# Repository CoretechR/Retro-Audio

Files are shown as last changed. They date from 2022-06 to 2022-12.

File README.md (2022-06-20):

# DIY Retro Audio Player

Inspired by 1980s tape recorders, this audio player was designed with ease of use and accessibility in mind. Despite its nostalgic appearance, it packs modern hardware. Powered by the ESP32, it plays music and audiobooks from a micro SD card, either on its internal speaker or though a headphone jack. A 2.8“ IPS screen and mechanical buttons make up the simplistic user interface. The software is built around the ESP32-audioI2S library by GitHub user Schreibfaul1.

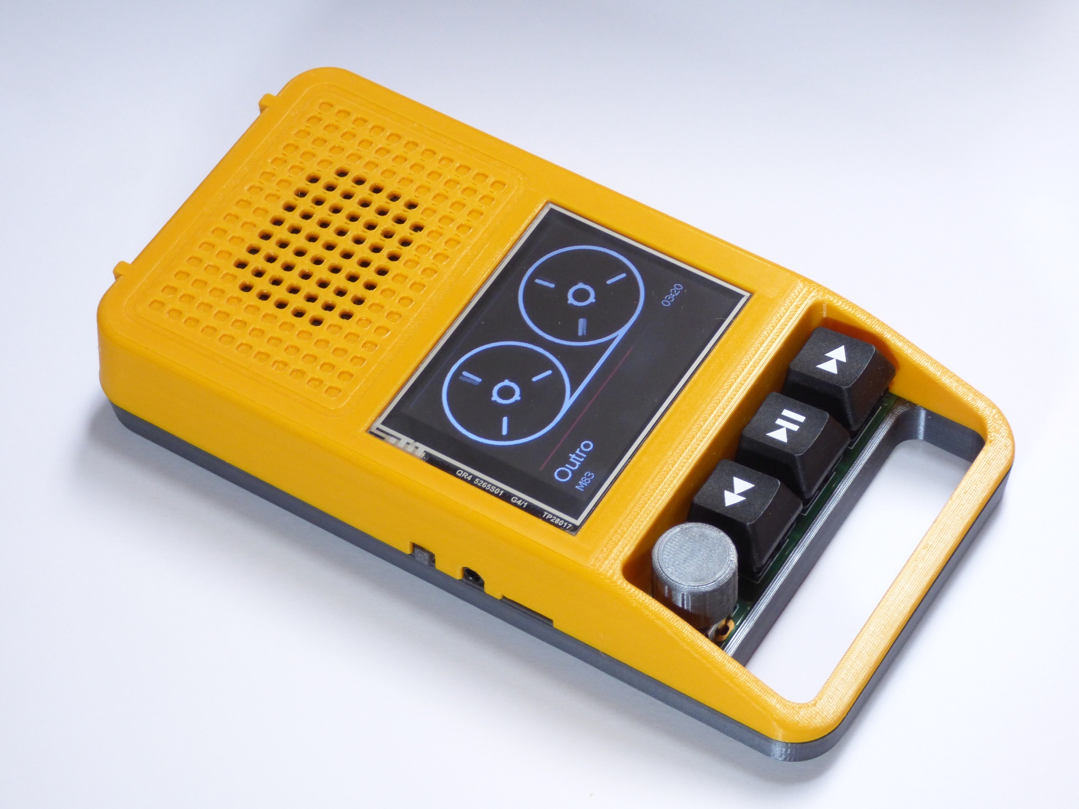
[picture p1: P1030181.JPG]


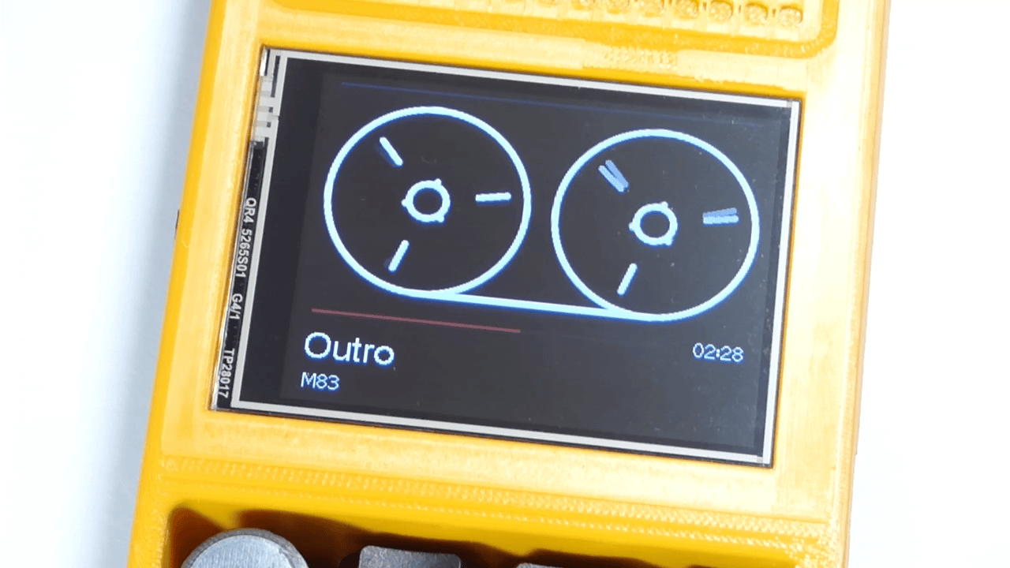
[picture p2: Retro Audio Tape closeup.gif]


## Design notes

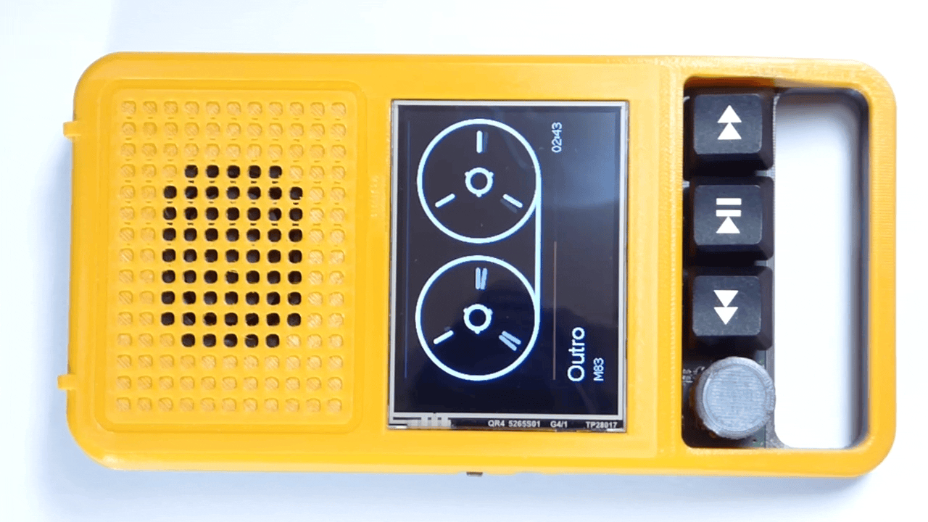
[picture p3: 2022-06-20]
Retro Audio Tape.gif

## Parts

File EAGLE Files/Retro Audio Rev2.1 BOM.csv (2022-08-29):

Qty | Value | Device | Package | Parts | Description | MPN | Supplier | Link
1 |  | DIODE_SOD-123FL | SOD-123FL | D1 | Diode | BAS116H;115 | Nexperia | https://www.mouser.de/ProductDetail/771-BAS116H115
1 |  | PINHD-1X9 | 1X09 | JP6 | PIN HEADER
2 |  | TERMBLOCK_1X2 | TERMBLOCK_1X2-3.5MM | J1; J3 | 3.5mm Terminal block | 6;91103E+11 | Würth Elektronik | https://www.mouser.de/ProductDetail/710-691103110002
1 |  | USB_C16PIN | USB-C-16P | J2 | USB Type C 16Pin Connector | USB4125-GF-A | GCT | https://www.mouser.de/ProductDetail/640-USB4125-GF-A
1 | 0 | 10KOHM-0603-1/10W-1% | 603 | R1 | 10kO resistor
6 | 0.1uF | 0.1UF-0603-25V-(+80/-20%) | 603 | C3; C4; C8; C11; C14; C16 | 0.1µF ceramic capacitors
1 | 1.0uF | 1.0UF-0805-25V-(+80/-20%) | 805 | C7 | 1µF ceramic capacitors
5 | 100k | R-US_R0603 | R0603 | R5; R6; R16; R25; R26 | RESISTOR; American symbol
13 | 10k | 10KOHM-0603-1/10W-1% | 603 | R2; R4; R7; R8; R9; R10; R11; R17; R18; R20; R23; R24; R30 | 10kO resistor
2 | 10nF | 1.0UF-0805-25V-(+80/-20%) | 805 | C9; C22 | 1µF ceramic capacitors
3 | 10uF | 10UF-0603-6.3V-20% | 603 | C5; C6; C20 | 10.0µF ceramic capacitors
1 | 10uF | 47PF-0603-50V-5% | 603 | C17 | 47pF ceramic capacitors
1 | 19269 | AUDIO_3.5MMJACK | 4UCONN_19269 | X2 | 3.5MM Audio Jack | SJ2-3593D-SMT-TR | CUI | https://www.mouser.de/ProductDetail/490-SJ2-3593D-SMT-TR
1 | 1M | R-US_R0603 | R0603 | R21 | RESISTOR; American symbol
1 | 2.2uF | 1.0UF-0805-25V-(+80/-20%) | 805 | C10 | 1µF ceramic capacitors
1 | 2.5A/30V | MOSFET-PCHANNELDMG2307L | SOT23-3 | Q1 | Generic PMOSFET | DMG2307L-7 | Diodes Inc | https://www.mouser.de/ProductDetail/621-DMG2307L-7
2 | 27 | 27OHM1/10W1%(0603)0603-RES | 603 | R13; R14 | RES-09334
1 | 309k | 10KOHM-0603-1/10W-1% | 603 | R28 | 10kO resistor
3 | 4.7uF | 4.7UF-6.3V-10%(0603)0603 | 0603-CAP | C2; C15; C21 | CAP-08280
1 | 4.7µH | WE-TPC_2813_744029004 | WE-TPC_2811/2813_OLD | L1 | SMD Shielded Tiny Power Inductor | 744029004 | Würth Elektronik | https://www.digikey.de/en/products/detail/w%C3%BCrth-elektronik/744029004/1638494
2 | 47pF | 47PF-0603-50V-5% | 603 | C12; C13 | 47pF ceramic capacitors
2 | 5.1k | 10KOHM-0603-1/10W-1% | 603 | R3; R19 | 10kO resistor
1 | 500mA | PTCSMD | PTC-1206 | F1 | Resettable Fuse PTC | 1206L050/15YR | Littelfuse | https://www.mouser.de/ProductDetail/576-1206L050-15YR
1 | 976k | 10KOHM-0603-1/10W-1% | 603 | R27 | 10kO resistor
1 | AOD417 | MOSFET-PTO252 | TO252 | Q3 | P-Channel Mosfet | AOD417 | Alpha&Omega | https://www.digikey.de/de/products/detail/alpha-omega-semiconductor-inc/AOD417/1855878
1 | AP2112K-3.3V | V_REG_LDOSMD | SOT23-5 | U3 | Voltage Regulator LDO | AP2112K-3.3TRG1 | Diodes Inc | https://www.mouser.de/ProductDetail/621-AP2112K-3.3TRG1
1 | BAT20J | DIODE-SCHOTTKY-BAT20J | SOD-323 | D3 | Schottky diodes in SFE's production catalog | BAT20JFILM | STM | https://www.mouser.de/ProductDetail/511-BAT20JFILM
3 | CHERRY-MX-LED | CHERRY-MX-LED | CHERRY-MX-LED | S3; S4; S5 |  | MX1A-E1NW | Cherry | https://www.mouser.de/ProductDetail/540-MX1A-E1NW
1 | ESP-WROOM-32 | ESP-WROOM-32 | ESP-WROOM-32 | U2 |  | ESP32-WROOM-32D-N4 | Espressif | https://www.mouser.de/ProductDetail/356-ESP32WROOM-32D
1 | FT231XS | FT231XS | SSOP20_L | U4 | FTDI FT231X Full Speed USB to Full-handshake UART | FT231XS-R | FTDI | https://www.mouser.de/ProductDetail/895-FT231XS-R
1 | MAX98357A | MAX98357A | TQFN-16 | IC1 | I2S DAC 3.2W (4-8ohm) | MAX98357AETE+T | Maxim | https://www.mouser.de/ProductDetail/700-MAX98357AETE%2bT
1 | MBT3904DW1T1 | MBT3904DW1T1 | SC70-6 | Q2 | MBT3904DW1 Dual NPN Transistors | MBT3904DW1T1G | OnSemi | https://www.mouser.de/ProductDetail/863-MBT3904DW1T1G
1 | MCP1640CT-I/CHY | MCP1640CT-I/CHY | SOT95P270X145-6N | U$1 | Synchronous Boost Regulator | MCP1640CT-I/CHY | Microchip | https://www.digikey.de/de/products/detail/microchip-technology/MCP1640CT-I-CHY/2258565
1 | OS102011MA1Q | OS102011MA1Q | OS102011MA1Q | SW1 | OS10201MA1Q through-hole right angle switch | OS102011MA1QN1 | C&K | https://www.mouser.de/ProductDetail/611-OS102011MA1QN1
1 | PEC11 | ENCODER_PLUS_SWITCH_BOURNS_PEC11 | PEC11+SWITCH | SW5 | Rotary Encoder with Built-In Switch | EC12E20-24P24C-SW | SRPassives | https://www.tme.eu/de/details/ec12e20-24p24c-sw/inkrementale-encoder/sr-passives/
1 | RESET | MOMENTARY-SWITCH-SPST-2-SMD-4.6X2.8MM | TACTILE_SWITCH_SMD_4.6X2.8MM | S1 | Momentary Switch (Pushbutton) - SPST - Two Circuits | KMR211GLFS | C&K | https://www.mouser.de/ProductDetail/611-KMR211G-LFS
1 | USD_CONNECTOR | USD_CONNECTOR | MICRO-SD-SOCKET-PP | JP3 | microSD Socket | MEM2061-01-188-00-A | GCT | https://www.mouser.de/ProductDetail/640-MEM20610118800A
Extra components that are not part of the PCB:
3 |  | Sparkfun Keycaps |  |  |  | PRT-15305 | Sparkfun | https://www.mouser.de/ProductDetail/474-PRT-15305
1 |  | Keystone Battery Holder |  |  |  | 2478 | Keystone | https://www.mouser.de/ProductDetail/534-2478
1 |  | Speaker |  |  |  | CDS-40304-L100 | CUI Devices | https://www.mouser.de/ProductDetail/490-CDS-40304-L100
1 |  | 2.8" 320x240px Display |  |  |  | 16446 | Waveshare | https://www.waveshare.com/2.8inch-resistive-touch-lcd.htm

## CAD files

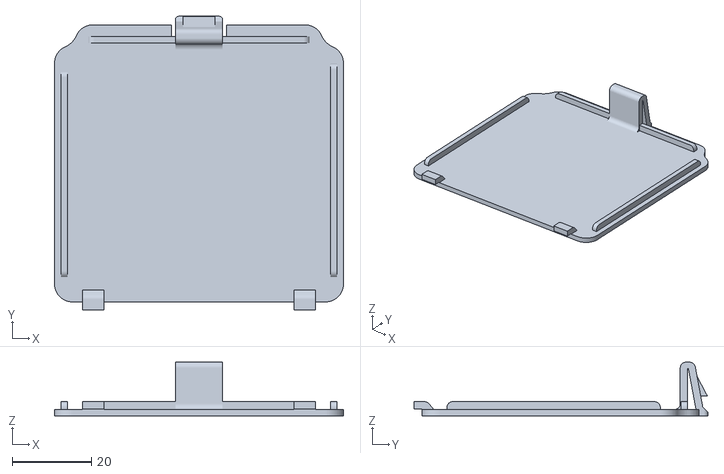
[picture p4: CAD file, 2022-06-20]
CAD Files/battery lid.stl
73.1 x 74.3 x 13.6

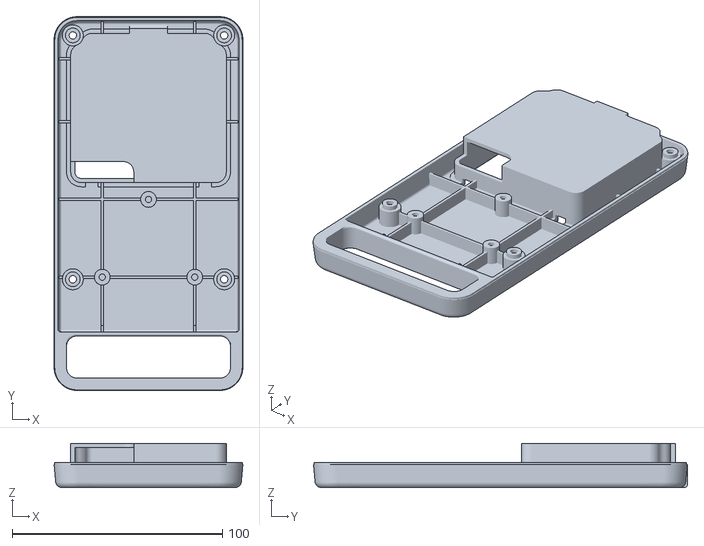
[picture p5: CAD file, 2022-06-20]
CAD Files/bottom shell.stl
89.8 x 177.9 x 21.0

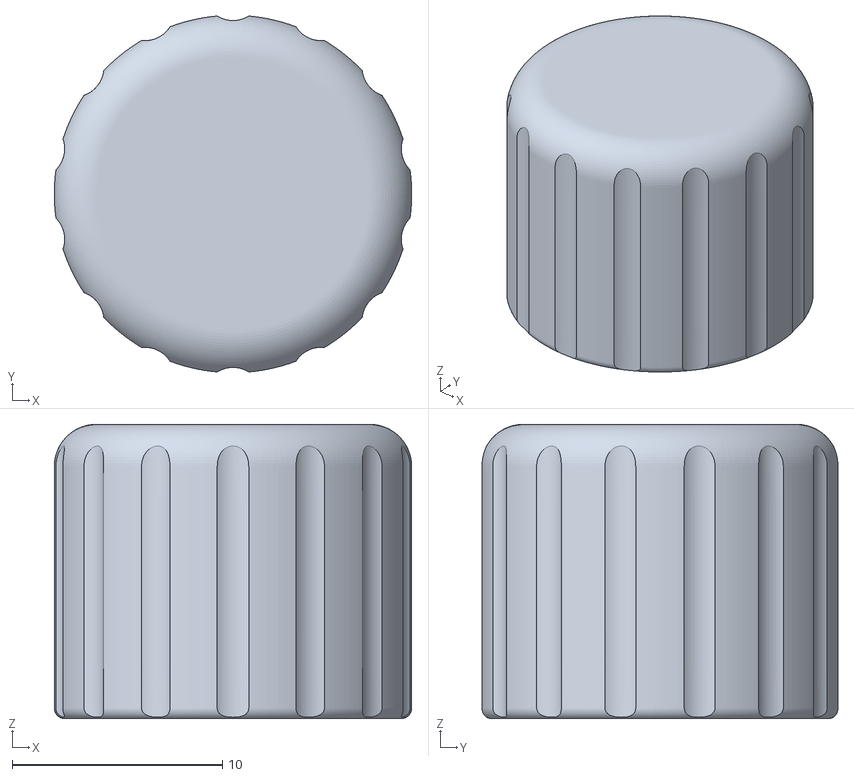
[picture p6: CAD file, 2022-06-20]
CAD Files/knob.stl
17.0 x 16.9 x 14.0

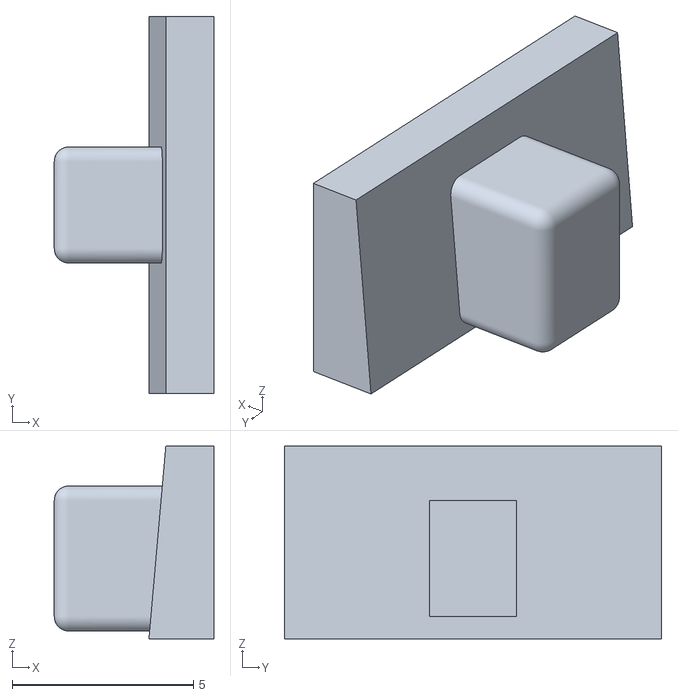
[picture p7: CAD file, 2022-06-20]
CAD Files/switch.stl
4.40 x 10.4 x 5.32

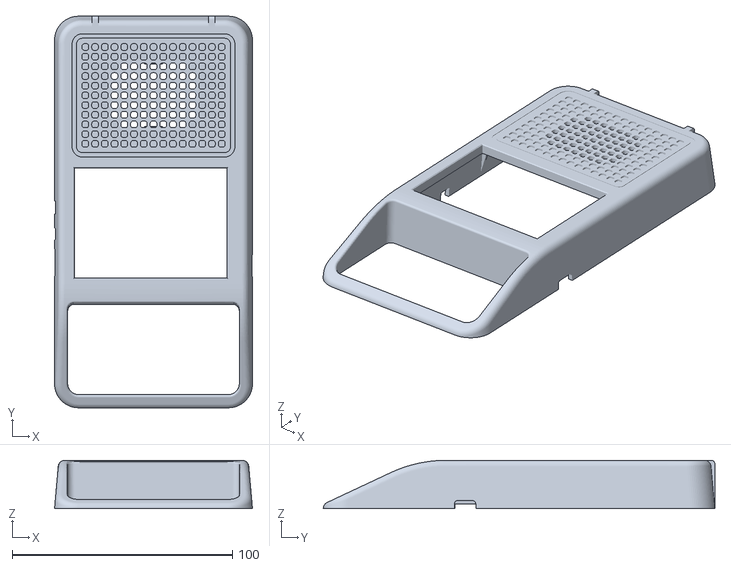
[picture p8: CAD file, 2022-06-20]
CAD Files/top shell.stl
90.0 x 178.0 x 22.0

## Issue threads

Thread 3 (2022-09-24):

What is C1, R12, R15, R27?

krokodil66, 2022-09-24:
Very cool project ;-)).

Could not find part "C1" in the BOM. It seems part of the Audio Output Stage. Is it a normal 0.1uF SMD capacitor? on Aisler.net is "\!0.01uF" shown in the part list.
Would be the following OK?:
Vishay | K103K10X7RF5UL2 | Multilayer Ceramic Capacitors MLCC - Leaded K 50V 10NF +/-10% X7R AMMO E3

R12, R15 is also missing on BOM. Is R27 976k or 10k?

CoretechR, 2022-09-24:
The parts marked with a "!" are not populated. I forgot to mention that in the documentation. I'm definitely going to update the files to add this, thanks!
Any yes, the values you found in the schematic are correct. The resistors are for configuring the output gain. The capacitor is not really necessary, I just left that in if the audio needs filtering.

Closed 2023-06-18.

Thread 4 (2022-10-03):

ILI9341 white screen

SteigerHSV, 2022-10-03:
Hey,

I have a problem uploading Retro-Audio using ESP32 dev board v4 and ILI9341 2.8" screen. After successful upload display shows only blank white screen. I also tested it using my other small screen 1.8" with ST7735 and it only shows small chunk of interface. ( i think because it should be 2.8" and i try it on 1.8" but it prove that esp32 works). I also tested ILI9341 on TFT_eSPI demos and they display normally.

I use User_Setup.h that is attech to .ino file only change driver from ST7789_2_DRIVER to ILI9341_2_DRIVER or ILI9341_DRIVER

CoretechR, 2022-10-03:
Hi, so you are editing the setup file in the library directory? There should be a few options specific to the ST7789, that you might have to change as well. Are you sure all the pin configurations are correctly defined in the setup file?
However if that same setup file works with the demos, it's a bit strange.

SteigerHSV, 2022-10-03:
When I open RetroAudio.ino it also open User_Setup.h that is different than TFT_eSPI library User_Setup.h. When I upload code, it use that User_Setup.h from RetroAudio.ino

i want to do photos for this issue so i setup everythig and weird things starts:

First i change  RetroAudio.ino User_Setup.h to work with ST7735 same as before, upload... white screen, change for ILI9341, upload, still white screen.

So i loaded clock demo, setup ST7735 in TFT_eSPI library User_Setup.h using default pinout, upload... works! but somehow image is mirrored? I check again User_Setup.h and find out I use by mistake ILI9341_DRIVER instead ST7735_DRIVER... it should not even work but somehow it was. I changed to ST7735_DRIVER upload, white screen again... I back to wrong driver and changed pinout to what it was in RetroAudio.ino User_Setup.h to checked if it still works, it was, so I copy TFT_eSPI library User_Setup.h to RetroAudio.ino  User_Setup.h upload and somehow it works but it cant clear background.

So if it works this way I decided to do same thing for ILI9341 and now it somehow works perfect!

It took me something like 4 days and it was not working at all and now it works and I dont even know why...

RAWJUNGLE, 2024-06-04:
I was able to get the ili9341 display up and running on the first try.

ESP32DEVKITv1

BL -> LED
RST-> to pin EN on ESP32

settings for arduino ide
Board - ESP32 WROOM DA Board (FOR ESP32DEVKITv1)
CPU Freaq - 240mHz
Core debug Level - none
Erase Flash - Enabled
Events run - Core0
Flash Freaq - 80Mhz
Flash Mode - QIO
Flash Size - 4MB
Arduino Runs - Core 1
Partition Scheme - NO OTA 2MB APP/ 2MB FATFS
UPLOAD SPEED - 115200

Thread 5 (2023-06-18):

Hey, I hope you are great.

AzraelOfficial, 2023-06-18:
This is amazing and so cute.

I wanted to know if I can have the audio tape gif to use in my project or at least tell me what to search on google to get me gifs of this example?

CoretechR, 2023-06-18:
Hi, the animation is rendered on the devices itself. It's not a gif or video.
But you can recreate the animation on your computer if you use this sketch in Processing.org:

```
void setup() {
  size(320, 240);
}

void draw() {
  background(0);
  fill(0);
  stroke(255);
  strokeWeight(5);

  pushMatrix();
  translate(80, height/2-20);
  ellipse(0, 0, 140, 140);
  ellipse(0, 0, 26, 26);
  rotate(frameCount / 40.0);
  for(int i=0; i<3; i++){
    line(0, 14, 0, 16);
    rotate(PI/3);
    line(0, 36, 0, 56);
    rotate(PI/3);
  }
  popMatrix();

  pushMatrix();
  translate(width-80, height/2-20);
  ellipse(0, 0, 140, 140);
  ellipse(0, 0, 26, 26);
  rotate(frameCount / 40.0);
  for(int i=0; i<3; i++){
    line(0, 14, 0, 16);
    rotate(PI/3);
    line(0, 36, 0, 56);
    rotate(PI/3);
  }
  popMatrix();

  line(80, height/2-20+70, width-80, height/2-20+70);
}
```
Here's a video that I recorded from the processing sketch:

https://github.com/CoretechR/Retro-Audio/assets/13223470/e31692c7-e014-4f21-ab43-6d0a39ad3103

AzraelOfficial, 2023-06-18:
Thanks 🙏🙌Sent from my iPadOn Jun 18, 2023, at 9:35 PM, Max K ***@***.***> wrote:
Hi, the animation is rendered on the devices itself. It's not a gif or video.
But you can recreate the animation on your computer if you use this sketch in Processing.org:
void setup() {
  size(320, 240);
}

void draw() {
  background(0);
  fill(0);
  stroke(255);
  strokeWeight(5);

  pushMatrix();
  translate(80, height/2-20);
  ellipse(0, 0, 140, 140);
  ellipse(0, 0, 26, 26);
  rotate(frameCount / 40.0);
  for(int i=0; i<3; i++){
    line(0, 14, 0, 16);
    rotate(PI/3);
    line(0, 36, 0, 56);
    rotate(PI/3);
  }
  popMatrix();

  pushMatrix();
  translate(width-80, height/2-20);
  ellipse(0, 0, 140, 140);
  ellipse(0, 0, 26, 26);
  rotate(frameCount / 40.0);
  for(int i=0; i<3; i++){
    line(0, 14, 0, 16);
    rotate(PI/3);
    line(0, 36, 0, 56);
    rotate(PI/3);
  }
  popMatrix();

  line(80, height/2-20+70, width-80, height/2-20+70);
}

Here's a video that I recorded from the processing sketch:
https://github.com/CoretechR/Retro-Audio/assets/13223470/e31692c7-e014-4f21-ab43-6d0a39ad3103

—Reply to this email directly, view it on GitHub, or unsubscribe.You are receiving this because you authored the thread.Message ID: ***@***.***>

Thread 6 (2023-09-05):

Question gain

olup, 2023-09-05:
Hi, I am using your schematics as an inspiration to design an audio product, and I am wondering where is the GAIN management (and SD_MODE). The label in the sheet goes nowhere:
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
Could you give some detail about it ?

Many thanks !

CoretechR, 2023-09-05:
Hi the gain is fixed to around 8dB by leaving the pin floating.
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
The audio volume is set via the i2s data. That's handled by the i2s library.

olup, 2023-09-05:
Many thanks. Same for the SD MODE ? You leave it floating for channel mixing ?

May I ask what is your experience with the max98357a with the headphones ? Is that good enough ?

Finally, I was meant to ask - what is the speaker you used in your project ? Are you happy with it ?

CoretechR, 2023-09-05:
Yes, the SD mode is set to mono audio, because there is only one audio driver. I built this mainly for listening to audiobooks and that works very well even with the internal speaker. But the audio quality is not so great. As there are only 21 volume levels, you really only have 5 or so levels for headphones because they are louder. It really depends on what you want to make.

CoretechR, 2023-09-05:
No problem, this is the speaker I used: https://www.mouser.de/ProductDetail/490-CDS-40304-L100

Closed 2023-09-05.

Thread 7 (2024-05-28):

Waveshare TFT LCD 3.2 white screen

legion3trunn3r, 2024-05-28:
I'm trying to print 'Hello World' on the screen Waveshare 3.2 LCD TFT, but instead it displays a white screen and that's it, I tried both ESP32 and Arduino Uno, I tried everything, but nothing helps

The link of my screen:  https://www.waveshare.com/3.2inch-320x240-touch-lcd-d.htm

Tried many of libraries and nothing works, what I can do to fix this problem?

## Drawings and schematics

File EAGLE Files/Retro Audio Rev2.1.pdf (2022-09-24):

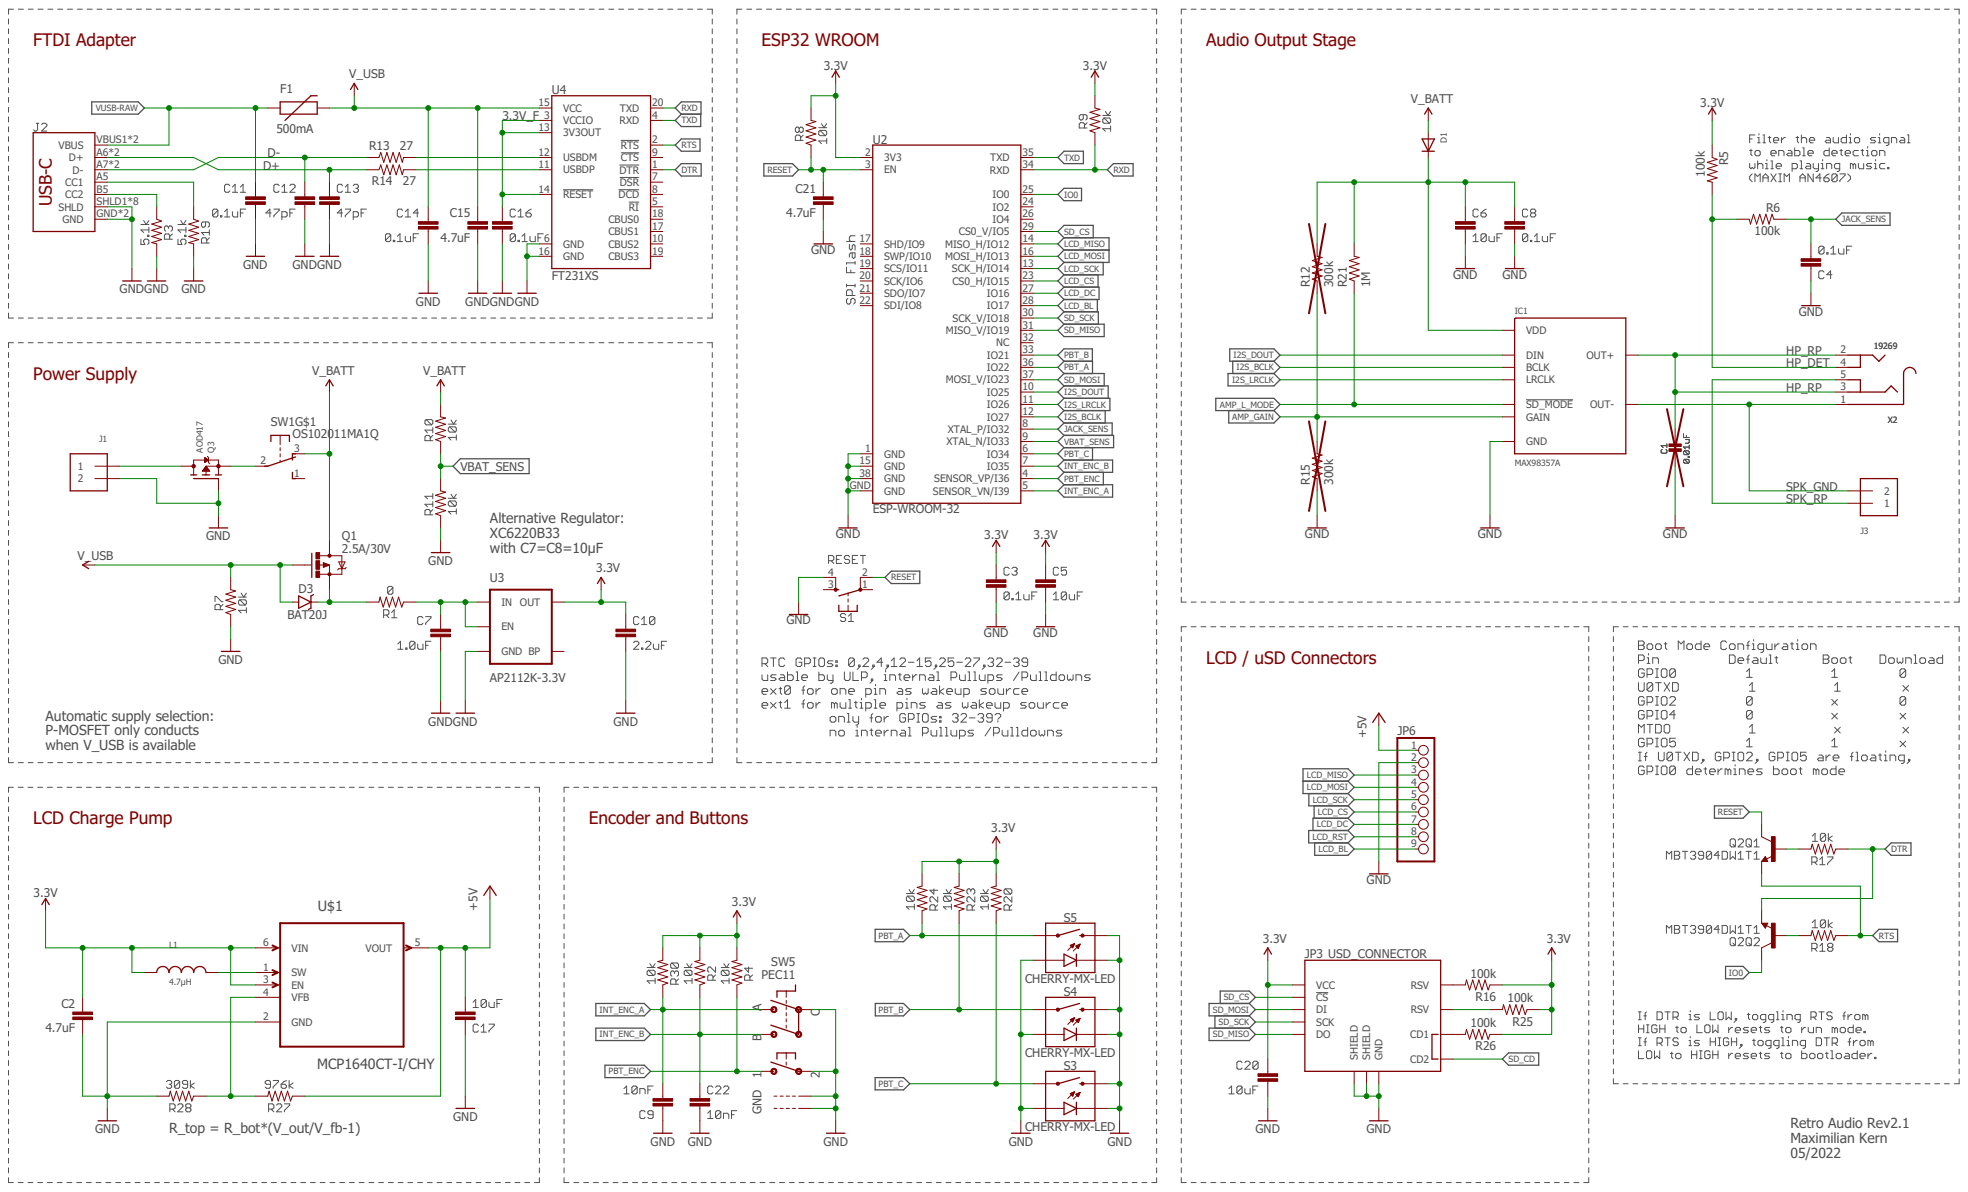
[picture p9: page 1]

Automatic supply selection: P-MOSFET only conducts when V_USB is available

Retro Audio Rev2.1 Maximilian Kern

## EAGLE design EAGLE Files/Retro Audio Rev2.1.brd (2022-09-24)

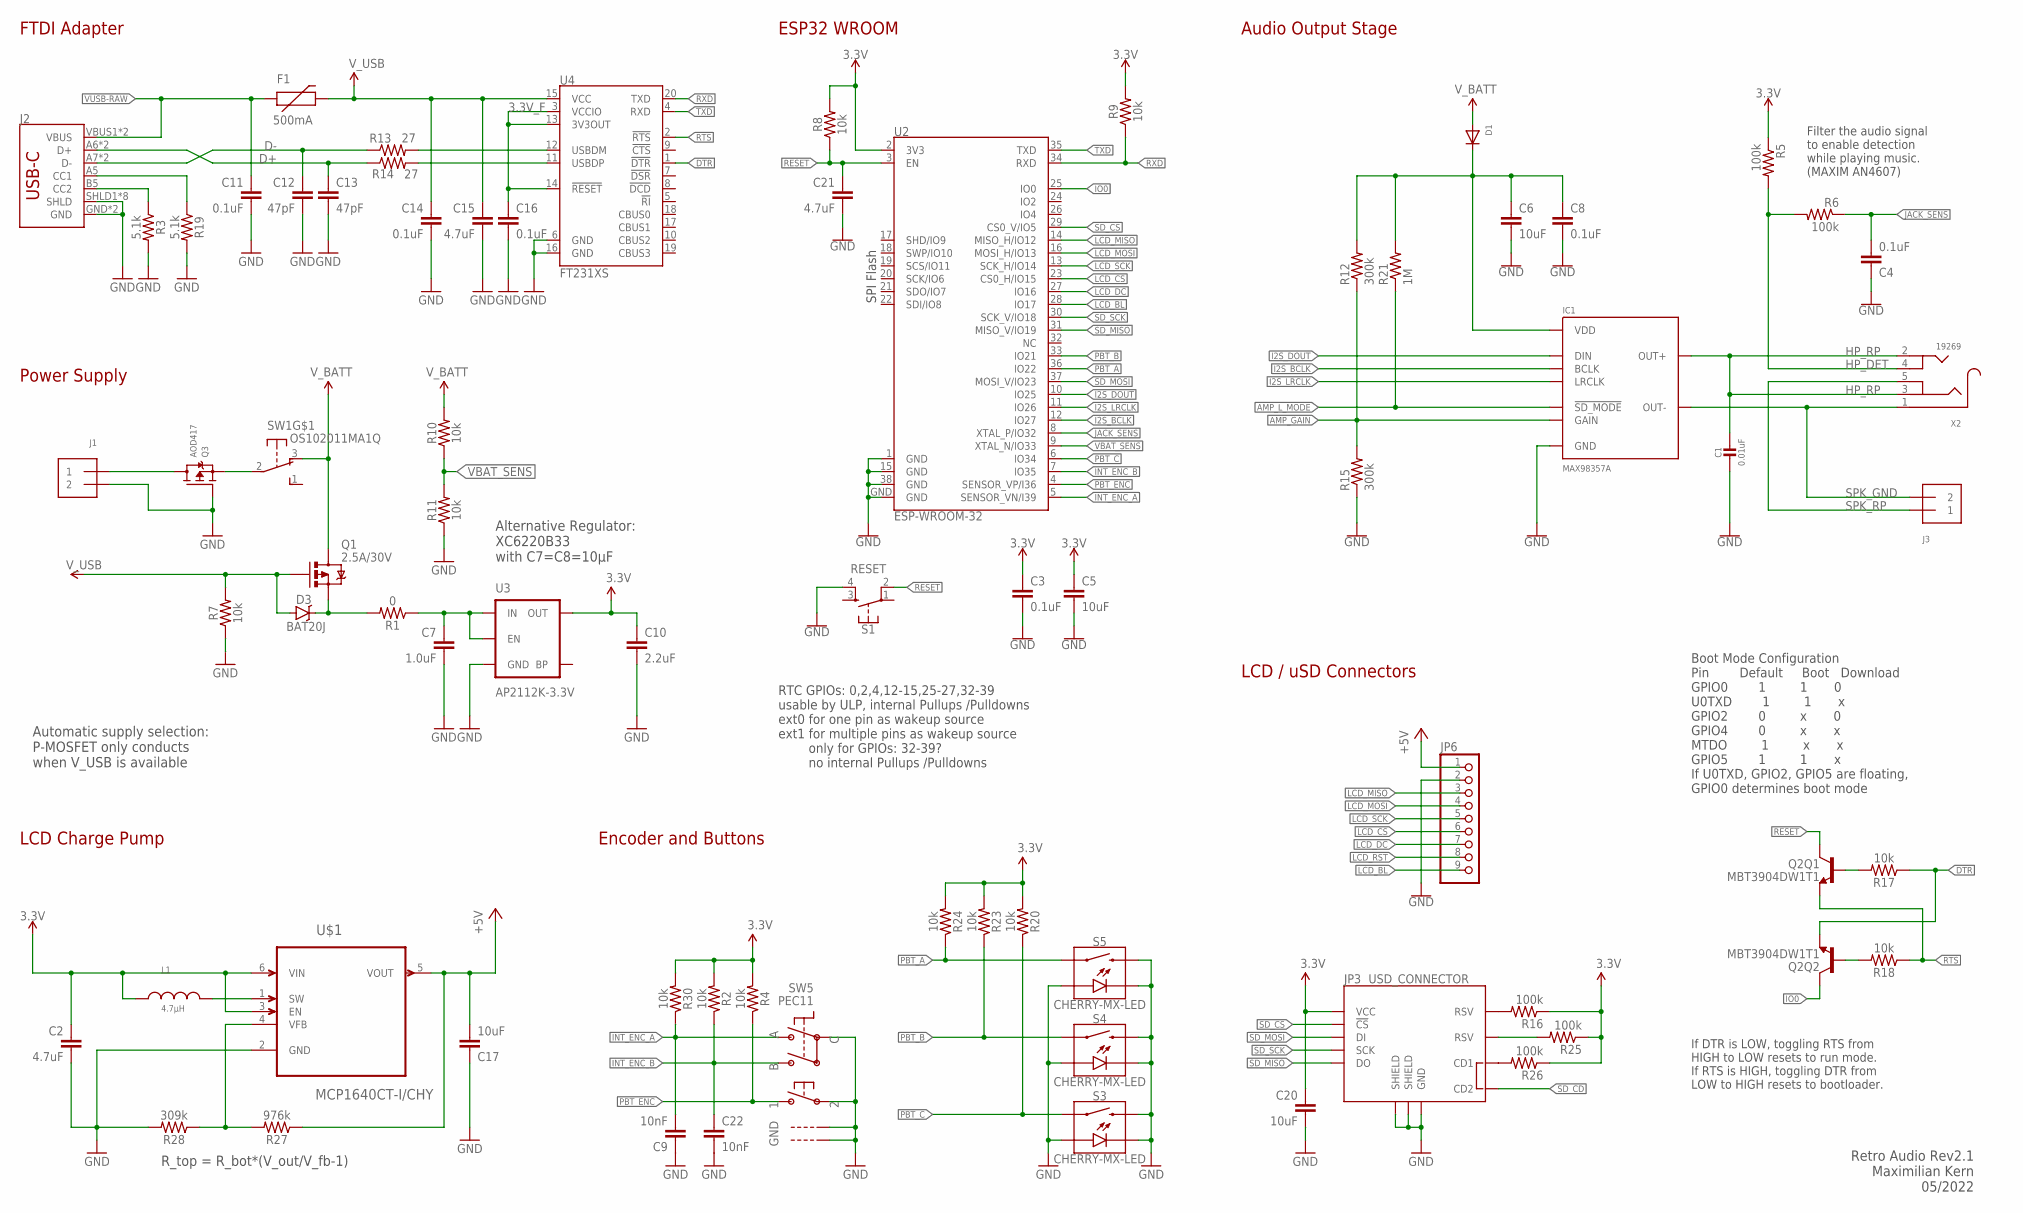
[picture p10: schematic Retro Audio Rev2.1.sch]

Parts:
C1: 0.01uF; 0603-NO
C2, C15, C21: 4.7uF; 0603-CAP
C3, C4, C8, C11, C14, C16: 0.1uF; 0603
C5, C6, C17, C20: 10uF; 0603
C7: 1.0uF; 0805
C9, C22: 10nF; 0805
C10: 2.2uF; 0805
C12, C13: 47pF; 0603
D1: DIODE_SOD-123FL; SOD-123FL
D3: BAT20J; SOD-323
F1: 500mA; PTC-1206
IC1: MAX98357A; TQFN-16
J1, J3: TERMBLOCK_1X2; TERMBLOCK_1X2-3.5MM
J2: USB_C16PIN; USB-C-16P
JP3: USD_CONNECTOR; MICRO-SD-SOCKET-PP
JP6: PINHD-1X9; 1X09
L1: 4.7µH; WE-TPC_2811/2813_OLD
Q1: 2.5A/30V; SOT23-3
Q2: MBT3904DW1T1; SC70-6
Q3: AOD417; TO252
R1: 0; 0603
R2, R4, R7, R8, R9, R10, R11, R17, R18, R20, R23, R24, R30: 10k; 0603
R3, R19: 5.1k; 0603
R5, R6, R16, R25, R26: 100k; R0603
R12, R15: 300k; R0603
R13, R14: 27; 0603
R21: 1M; R0603
R27: 976k; 0603
R28: 309k; 0603
S1: RESET; TACTILE_SWITCH_SMD_4.6X2.8MM
S3, S4, S5: CHERRY-MX-LED
SW1: OS102011MA1Q
SW5: PEC11; PEC11+SWITCH
U2: ESP-WROOM-32
U3: AP2112K-3.3V; SOT23-5
U4: FT231XS; SSOP20_L
U$1: MCP1640CT-I/CHY; SOT95P270X145-6N
X2: 19269; 4UCONN_19269

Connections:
3.3V: C2.1, C3.1, C5.1, C10.1, C20.1, JP3.VCC, L1.1, R2.2, R4.2, R5.1, R8.2, R9.2, R16.1, R20.2, R23.2, R24.2, R25.1, R26.1, R30.2, U2.2 (3V3), U3.5 (OUT), U$1.3 (EN), U$1.6 (VIN)
3.3V_F: C16.1, U4.3 (VCCIO), U4.13 (3V3OUT), U4.14 (!RESET)
+5V: C17.2, JP6.1, R27.1, U$1.5 (VOUT)
AMP_GAIN: IC1.P$2 (GAIN), R12.1, R15.2
AMP_L_MODE: IC1.P$4 (!SD_MODE), R21.1
B_VFB: R27.2, R28.1, U$1.4 (VFB)
D+: C13.1, J2.A6 (D+), J2.B6 (D+), R14.1
D-: C12.1, J2.A7 (D-), J2.B7 (D-), R13.1
DTR: Q2.1 (E), R17.1, U4.1 (!DTR)
GND: C1.2, C2.2, C3.2, C4.1, C5.2, C6.2, C7.2, C8.2, C9.1, C10.2, C11.2, C12.2, C13.2, C14.2, C15.2, C16.2, C17.1, C20.2, C21.2, C22.2, IC1.P$3 (GND), IC1.P$11 (GND), IC1.P$15 (GND), IC1.P$EP (GND), J1.2, J2.GND, J2.GND2 (GND), J2.SHLD1 (SHLD), J2.SHLD2 (SHLD), J2.SHLD3 (SHLD), J2.SHLD4 (SHLD), J2.SHLD5 (SHLD), J2.SHLD6 (SHLD), J2.SHLD7 (SHLD), J2.SHLD8 (SHLD), JP3.GND, JP3.GND1 (SHIELD), JP3.GND3 (SHIELD), JP6.2, Q3.1 (G), R3.2, R7.1, R11.1, R15.1, R19.2, R28.2, S1.4, S3.A, S3.K (C), S3.S2, S4.A, S4.K (C), S4.S2, S5.A, S5.K (C), S5.S2, SW5.P$2, SW5.P$C, SW5.P$GND1, SW5.P$GND2, U2.1 (GND), U2.15 (GND), U2.38 (GND), U2.GND, U3.2 (GND), U4.6 (GND), U4.16 (GND), U$1.2 (GND)
HP_DET: R5.2, R6.2, X2.4
HP_RP: C1.1, IC1.P$9 (OUT+), X2.2, X2.3
I2S_BCLK: IC1.P$16 (BCLK), U2.12 (IO27)
I2S_DOUT: IC1.P$1 (DIN), U2.10 (IO25)
I2S_LRCLK: IC1.P$14 (LRCLK), U2.11 (IO26)
INT_ENC_A: C9.2, R30.1, SW5.P$A, U2.5 (SENSOR_VN/I39)
INT_ENC_B: C22.1, R2.1, SW5.P$B, U2.7 (IO35)
IO0: Q2.6 (C), U2.25 (IO0)
JACK_SENS: C4.2, R6.1, U2.8 (XTAL_P/IO32)
LCD_BL: JP6.9, U2.28 (IO17)
LCD_CS: JP6.6, U2.23 (CS0_H/IO15)
LCD_DC: JP6.7, U2.27 (IO16)
LCD_MISO: JP6.3, U2.14 (MISO_H/IO12)
LCD_MOSI: JP6.4, U2.16 (MOSI_H/IO13)
LCD_RST: JP6.8
LCD_SCK: JP6.5, U2.13 (SCK_H/IO14)
unnamed: J1.1, Q3.3 (D)
unnamed: C7.1, R1.1, U3.1 (IN), U3.3 (EN)
unnamed: Q3.2 (S), SW1.2
unnamed: D3.C, Q1.2 (S), R1.2
unnamed: JP3.RSV1 (RSV), R16.2
unnamed: R13.2, U4.12 (USBDM)
unnamed: R14.2, U4.11 (USBDP)
unnamed: J2.A5 (CC1), R19.1
unnamed: Q2.5 (B), R17.2
unnamed: J2.B5 (CC2), R3.1
unnamed: Q2.2 (B), R18.2
unnamed: JP3.RSV2 (RSV), R25.2
unnamed: JP3.CD1, R26.2
unnamed: L1.2, U$1.1 (SW)
unnamed: C6.1, C8.1, D1.C, IC1.P$7 (VDD), IC1.P$8 (VDD), R12.2, R21.2
PBT_A: R24.1, S5.S1, U2.36 (IO22)
PBT_B: R23.1, S4.S1, U2.33 (IO21)
PBT_C: R20.1, S3.S1, U2.6 (IO34)
PBT_ENC: R4.1, SW5.P$1, U2.4 (SENSOR_VP/I36)
RESET: C21.1, Q2.3 (C), R8.1, S1.2, U2.3 (EN)
RTS: Q2.4 (E), R18.1, U4.2 (!RTS)
RXD: R9.1, U2.34 (RXD), U4.20 (TXD)
SD_CD: JP3.CD2
SD_CS: JP3.CS (!CS), U2.29 (CS0_V/IO5)
SD_MISO: JP3.DO, U2.31 (MISO_V/IO19)
SD_MOSI: JP3.DI, U2.37 (MOSI_V/IO23)
SD_SCK: JP3.SCLK (SCK), U2.30 (SCK_V/IO18)
SPK_GND: IC1.P$10 (OUT-), J3.2, X2.1
SPK_RP: J3.1, X2.5
TXD: U2.35 (TXD), U4.4 (RXD)
VBAT_SENS: R10.1, R11.2, U2.9 (XTAL_N/IO33)
VUSB-RAW: C11.1, F1.1, J2.VBUS1 (VBUS), J2.VBUS2 (VBUS)
V_BATT: D1.A, Q1.3 (D), R10.2, SW1.3 (O)
V_USB: C14.1, C15.1, D3.A, F1.2, Q1.1 (G), R7.2, U4.15 (VCC)

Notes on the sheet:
ESP32 WROOM
Boot Mode Configuration Pin Default Boot Download GPIO0 1 1 0 U0TXD 1 1 x GPIO2 0 x 0 GPIO4 0 x x MTDO 1 x x GPIO5 1 1 x If U0TXD, GPIO2, GPIO5 are floating, GPIO0 determines boot mode
If DTR is LOW, toggling RTS from HIGH to LOW resets to run mode. If RTS is HIGH, toggling DTR from LOW to HIGH resets to bootloader.
Power Supply
FTDI Adapter
Encoder and Buttons
LCD Charge Pump
RTC GPIOs: 0,2,4,12-15,25-27,32-39 usable by ULP, internal Pullups /Pulldowns ext0 for one pin as wakeup source ext1 for multiple pins as wakeup source only for GPIOs: 32-39? no internal Pullups /Pulldowns
SPI Flash
Retro Audio Rev2.1 Maximilian Kern 05/2022
Alternative Regulator: XC6220B33 with C7=C8=10µF
Automatic supply selection: P-MOSFET only conducts when V_USB is available
Audio Output Stage
R_top = R_bot*(V_out/V_fb-1)
LCD / uSD Connectors
Filter the audio signal to enable detection while playing music. (MAXIM AN4607)

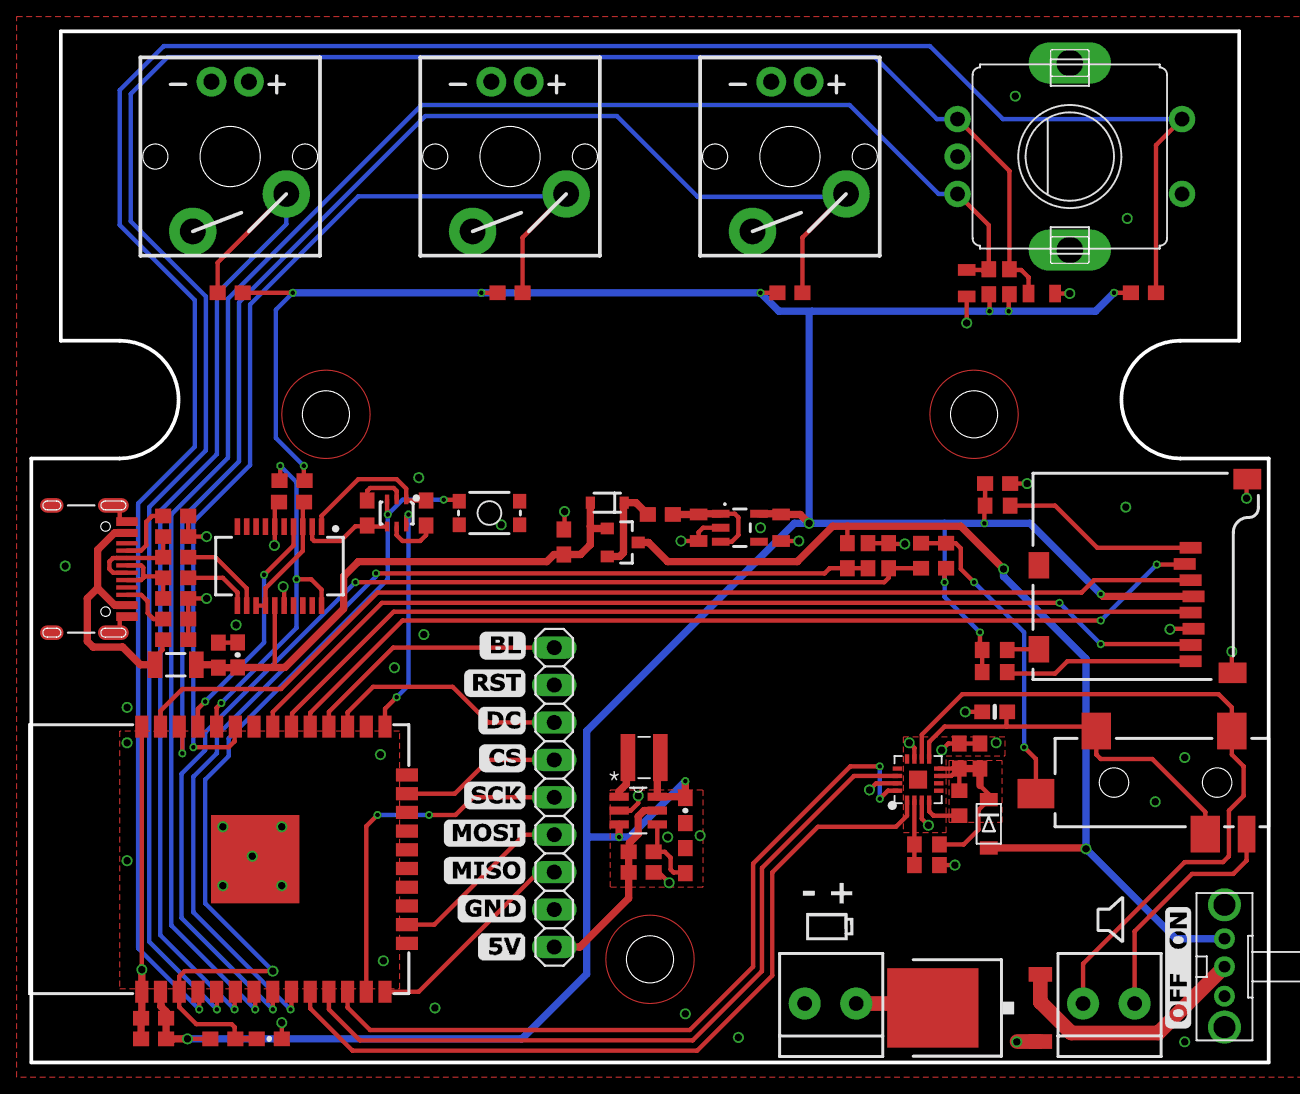
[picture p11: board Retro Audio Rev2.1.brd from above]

Board: 2 copper layers, 84.0 x 70.0 mm, 72 parts (0 on the bottom side), 58 nets.

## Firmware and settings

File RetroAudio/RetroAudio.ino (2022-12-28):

// 2022 Maximilian Kern		
#include <Arduino.h>
#include <JC_Button.h> // https://github.com/JChristensen/Button
#include "Audio.h" // https://github.com/schreibfaul1/ESP32-audioI2S
#include "SPI.h"
#include "SD.h"
#include "FS.h"
#include <TFT_eSPI.h> // Hardware-specific library

#define BLACK 0
#define WHITE 1

#define LIGHTGREEN 0x05AE
#define DARKGREEN  0x022B
#define LIGHTPINK  0xC169
#define DARKPINK   0x30A4
#define LIGHTBLUE  0x6C7F
#define DARKBLUE   0x1929

#define WIDTH    320
#define HEIGHT   240

#define I2S_DOUT     25
#define I2S_BCLK     27
#define I2S_LRC      26

#define SD_CS        5
#define SD_MOSI      23
#define SD_MISO      19
#define SD_SCK       18

//#define LCD_DC       16 // defined in TFT_eSPI User_Setup.h
//#define LCD_CS       15
//#define LCD_MOSI     13
//#define LCD_SCK      14
//#define LCD_MISO     12
#define LCD_BL     17 

#define ABUT      22
#define BBUT      21
#define CBUT      34
#define ENCINTA   39
#define ENCINTB   35
#define ENCBUT    36

#define JACK_SENS 32
#define VBAT_SENS 33

Button buttonA(ABUT, false, true, 5); //pin, pullup, invert, debounce
Button buttonB(BBUT, false, true, 5);
Button buttonC(CBUT, false, true, 5);
Button buttonENC(ENCBUT, false, true, 5);

TFT_eSPI tft = TFT_eSPI();       // Invoke custom library
TFT_eSprite img = TFT_eSprite(&tft);
unsigned int spriteX = 118; //Tape animation sprite size
const int tapePosY = 84; //Tape animation Y Center Position

Audio audio;
boolean _f_eof = false;
unsigned long savePosFlag = 60000;

int volume_hp = 1;
int volume_spk = 3;
const int volume_hp_max = 4;
const int volume_spk_max = 21;
boolean volumeChanged = true;
unsigned long saveVolFlag;

String tracks[255];
unsigned int trackTotal = 0;
int currentTrackNum = 0;
String currentTitle;
String currentArtist;

boolean headphones = true;

unsigned int batteryVoltageMilliVolts;
#define batteryVoltageGood 4500
#define batteryVoltageBad 4000
boolean batteryLow = false;

// Power saving
boolean screenOff = false;
unsigned int screenOffTime = 15000;
unsigned long screenOffFlag = screenOffTime;

// interrupt service routine vars
boolean A_set = false;            
boolean B_set = false;

//****************************************************************************************
//                                    HELPER FUNCTIONS                                   *
//****************************************************************************************

void IRAM_ATTR isr_enca(){
  if( digitalRead(ENCINTA) != A_set ) {  // debounce once more
    A_set = !A_set;
    // adjust counter + if A leads B
    if( A_set && !B_set ){
      if(headphones){
        if(volume_hp++ >= volume_hp_max) volume_hp = volume_hp_max;
      }
      else{
        if(volume_spk++ >= volume_spk_max) volume_spk = volume_spk_max;
      }
    }
    volumeChanged = true;
  }
}

void IRAM_ATTR isr_encb(){
  if( digitalRead(ENCINTB) != B_set ) {
    B_set = !B_set;
    //  adjust counter - 1 if B leads A
    if( B_set && !A_set ){
      if(headphones){
        if(volume_hp-- <= 0) volume_hp = 0;
      }
      else{
        if(volume_spk-- <= 0) volume_spk = 0;
      }
    }
    volumeChanged = true;
  }
} 

void turnScreenOff(boolean powerdown){
  // low Power mode
  if(powerdown){
    digitalWrite(LCD_BL, LOW);  
    //setCpuFrequencyMhz(80);
    screenOff = true;
  }
  // high power mode
  else {
    digitalWrite(LCD_BL, HIGH);  
    //setCpuFrequencyMhz(240);
    screenOffFlag = millis() + screenOffTime;
    screenOff = false;
  }
}

void drawTitleInfo(){
  tft.setTextPadding(312-18);
  tft.setTextDatum(TL_DATUM);
  tft.setTextColor(0xFFFF, TFT_BLACK);
  if(currentTitle.length() > 21) currentTitle = currentTitle.substring(0, 20) + "...";
  tft.drawString(currentTitle, 8, 190, 4);
  tft.drawString(currentArtist, 10, 218, 2);
}

void drawProgressBar(){
  static int progressBar;
  const int progressBarWidth = 235;
  unsigned long currentPos = audio.getAudioCurrentTime();
  unsigned long audioDuration = audio.getAudioFileDuration();

  progressBar = map(currentPos, 0, audioDuration, 1, progressBarWidth); 
  progressBar = min(progressBar, progressBarWidth);
  tft.fillRect(10, 174, progressBar+1, 2, LIGHTPINK);
  tft.fillRect(11 + progressBar, 174, progressBarWidth-progressBar, 2, DARKPINK);
  tft.setTextPadding(60);
  tft.setTextDatum(TR_DATUM);
  tft.setTextColor(TFT_WHITE, TFT_BLACK);
  char posString[16];
  // Hide hour digits until needed
  if(currentPos < 3600) sprintf(posString, "%02d:%02d", int(currentPos/60)%60, int(currentPos%60));
  else sprintf(posString, "%2d:%02d:%02d", int(currentPos/3600), int(currentPos/60)%60, int(currentPos%60));
  tft.drawString(posString, 310, 167, 2);
}

bool isMusic(const char* filename) {
  int8_t len = strlen(filename);
  bool result;
  if (  strstr(filename + (len - 4), ".mp3")
     || strstr(filename + (len - 4), ".wav")
    ) {
    result = true;
  } else {
    result = false;
  }
  return result;
}

void scanSD(){
  File root = SD.open("/");
  root.rewindDirectory();
  for(int i = 0; i < 255; i++){
    File entry =  root.openNextFile();
    if(!entry){
      break;
    }
    else if(!entry.isDirectory() && isMusic(entry.name())){
      tracks[trackTotal] = entry.name();
      Serial.println(entry.name());
      trackTotal += 1;
    }
  }
  root.close();
}

String getSaveFileName(String audioFileName){
  String tempString = audioFileName;
  tempString.replace(audioFileName.c_str() + (audioFileName.length() - 4), ".txt");
  tempString = "/persistence/" + tempString;
  return tempString;
}

void nextTrack(){
  if(currentTrackNum++ >= trackTotal-1) currentTrackNum = 0;
}

void prevTrack(){
  if(currentTrackNum-- <= 0) currentTrackNum = trackTotal-1;
}

void savePosition(){
  String saveFileName = getSaveFileName(tracks[currentTrackNum]);
    
  File saveFile = SD.open(saveFileName, FILE_APPEND);
  if(saveFile){
      char posString[10];
      sprintf(posString, "%010d", audio.getFilePos());
      saveFile.println(posString);
      saveFile.close(); // close the file:
      Serial.print("File saved at position ");
      Serial.println(posString);
  }
  saveFile.close();
}

unsigned int restorePosition(String tempFileName){
  String tempSaveFile = getSaveFileName(tempFileName);
  unsigned int filePos = 0;

  File saveFile = SD.open(tempSaveFile, FILE_READ);
  if(saveFile){
    saveFile.seek(saveFile.size()-12); // go to the last 10-char line
    filePos = saveFile.readStringUntil('\n').toInt();

    Serial.print("File restored to Position ");
    Serial.println(filePos);
  }
  return filePos;
}

void saveVolume(){
  String saveFileName = "/persistence/setting_volume.txt";
    
  File saveFile = SD.open(saveFileName, FILE_APPEND);
  if(saveFile){
      char volString[10];
      sprintf(volString, "%02d%02d", volume_spk, volume_hp);
      saveFile.println(volString);
      saveFile.close();
      Serial.print("Volume saved: ");
      Serial.println(volString);
  }
  saveFile.close();
}

unsigned int restoreVolume(){
  String tempSaveFile = "/persistence/setting_volume.txt";
  unsigned int filePos = 0;

  File saveFile = SD.open(tempSaveFile, FILE_READ);
  if(saveFile){
    saveFile.seek(saveFile.size()-6); // go to the last 6-char line
    String tempString;
    tempString = saveFile.readStringUntil('\n');
    volume_spk = tempString.substring(0, 2).toInt();
    volume_hp = tempString.substring(2, 4).toInt();

    Serial.print("volume restored to spk:");
    Serial.print(volume_spk);
    Serial.print(" and hp:");
    Serial.println(volume_hp);
  }
  return filePos;
}

void initGraphics(){  

  //Draw Background
  tft.fillRect(0, 0, 320, 240, 0x0000);
  
  tft.fillSmoothCircle(320-80, tapePosY, 72, 0xFFFF); //Outer circle
  tft.fillSmoothCircle(320-80, tapePosY, 67, 0x0000, 0xFFFF);
  tft.fillSmoothCircle(80, tapePosY, 72, 0xFFFF); //Outer circle
  tft.fillSmoothCircle(80, tapePosY, 67, 0x0000, 0xFFFF);
  tft.fillRect(80, tapePosY+68, 320-80-80, 5, 0xFFFF); 
}

void drawTapeSpools(){

  img.fillSprite(TFT_TRANSPARENT);
  img.fillCircle(59, 59, 59, 0x0000);
  audio.loop();
  static float angle = 0;  
  static unsigned long oldMillis = millis();  
  if(audio.isRunning()) angle -= float(millis() - oldMillis)/600;
  oldMillis = millis();
  for(int i = 1; i <= 3; i++){
    audio.loop();
    float angleOffset = i*TWO_PI/3;    
    float s = sin(angle+angleOffset);
    float c = cos(angle+angleOffset);
    audio.loop();
    img.drawWideLine(spriteX/2+(0*c-36*s), spriteX/2+(0*s+36*c), spriteX/2+(0*c-56*s), spriteX/2+(0*s+56*c), 5, 0xFFFF, 0x0000);
    audio.loop();
    s = sin(angle+angleOffset+1.0472);
    c = cos(angle+angleOffset+1.0472);
    img.drawWideLine(spriteX/2+(0*c-14*s), spriteX/2+(0*s+14*c), spriteX/2+(0*c-16*s), spriteX/2+(0*s+16*c), 5, 0xFFFF, 0x0000);    
    audio.loop();
  }
  if(angle > 2*PI) angle = 0;
  audio.loop();
  img.fillSmoothCircle(spriteX/2, spriteX/2, 15, 0xFFFF); //Inner circle
  img.fillSmoothCircle(spriteX/2, spriteX/2, 10, 0x0000, 0xFFFF);
  audio.loop();
  img.pushSprite(320-80-spriteX/2, tapePosY-spriteX/2, TFT_TRANSPARENT);
  img.pushSprite(80-spriteX/2, tapePosY-spriteX/2, TFT_TRANSPARENT);
}

void setup() {

  pinMode(LCD_BL, OUTPUT);
  pinMode(ABUT, INPUT);
  pinMode(BBUT, INPUT);
  pinMode(CBUT, INPUT);
  pinMode(ENCINTA, INPUT);
  pinMode(ENCINTB, INPUT);
  pinMode(ENCBUT, INPUT);
  pinMode(SD_CS, OUTPUT);

  attachInterrupt(ENCINTA, isr_enca, CHANGE);
  attachInterrupt(ENCINTB, isr_encb, CHANGE);


  Serial.begin(115200);
  Serial.println("gestartet!");

  tft.init();
  tft.setRotation(3);
  tft.fillScreen(TFT_BLACK);
  tft.setSwapBytes(true);


  digitalWrite(SD_CS, HIGH);
  SPI.begin(SD_SCK, SD_MISO, SD_MOSI);
  SD.begin(SD_CS);
  scanSD();
  //create a folder to store save files
  if(!SD.exists("/persistence"))  SD.mkdir("/persistence");    

  audio.setPinout(I2S_BCLK, I2S_LRC, I2S_DOUT);
  restoreVolume();
  
  audio.setPinout(I2S_BCLK, I2S_LRC, I2S_DOUT);
  audio.setVolume(volume_hp);

  audio.connecttoSD(tracks[currentTrackNum].c_str(), restorePosition(tracks[currentTrackNum]));

  //draw Background
  initGraphics();

  // turn on display after initialization
  digitalWrite(LCD_BL, HIGH);  
  
  img.setColorDepth(8);  
  img.createSprite(spriteX, spriteX);

  //delay(200);
  /* Änderung für Hörbuch Modus
  audioPauseResume();
  */
}

void loop()
{
  audio.loop();

  Serial.println(audio.getAudioCurrentTime());
  
  // Turn screen off after a timeout
  if(!screenOff && millis() > screenOffFlag){
    turnScreenOff(true);
  }

  
  //check battery
  batteryVoltageMilliVolts = 2*analogReadMilliVolts(VBAT_SENS);
  if(batteryVoltageMilliVolts < batteryVoltageBad && !batteryLow){
    batteryLow = true;
    // draw low battery symbol
    tft.drawRect(WIDTH-15, HEIGHT-25, 10, 19, LIGHTPINK);
    tft.fillRect(WIDTH-13, HEIGHT-27, 6, 2, LIGHTPINK);
    tft.fillRect(WIDTH-13, HEIGHT-11, 6, 3, LIGHTPINK);
  }
  else if(batteryVoltageMilliVolts > batteryVoltageGood && batteryLow){
    batteryLow = false;
    // erase low battery symbol
    tft.fillRect(WIDTH-15, HEIGHT-27, 10, 21, TFT_BLACK);
  }
  
  //check headphone jack
  if(analogReadMilliVolts(JACK_SENS) > 2800){
    if(headphones != true){
      headphones = true; 
      volumeChanged = true;   
    }
  }
  else{
    if(headphones != false){
      headphones = false; 
      volumeChanged = true;   
    }
  }

  // set volume and draw volume bar
  if(volumeChanged){
    turnScreenOff(false);    
    int volumeBarWidth = 0;
    if(headphones){ 
      audio.setVolume(volume_hp);
      volumeBarWidth = map(volume_hp, 0, volume_hp_max, 0, 300);
    }
    else {
      audio.setVolume(volume_spk);
      volumeBarWidth = map(volume_spk, 0, volume_spk_max, 0, 300);
    }
    
    tft.fillRect(10, 0, volumeBarWidth, 2, LIGHTGREEN);
    tft.fillRect(10+volumeBarWidth, 0, 300-volumeBarWidth, 2, DARKGREEN);

    saveVolFlag = millis() + 10000; // save volume only after 10s

    volumeChanged = false; // reset volume flag
  }
  
  // handle end of file
  if(_f_eof == true){
    audio.pauseResume();
    nextTrack(); //remove this line to repeat track
    audio.connecttoSD(tracks[currentTrackNum].c_str(), restorePosition(tracks[currentTrackNum]));
    _f_eof = false;
  }

  // check if it's time to save the volume
  // do this only when necessary to reduce SD wear and visual glitches
  if(millis() > saveVolFlag){
    saveVolume();
    saveVolFlag = millis() + 3600000; // reset the flag far away
  }
  
  // check if it's time to save the file position
  if(millis() > savePosFlag && audio.isRunning()){    
    savePosition();
    savePosFlag = millis() + 60000; // set flag to save settings to 60 seconds from now
  }
  
    // animate tape spools
  drawTapeSpools();
  
  //draw progress bar
  if(audio.isRunning())  drawProgressBar();

  if(buttonA.pressedFor(1000)){
    turnScreenOff(false);    
    audio.setTimeOffset(-30);
    buttonA.read();
  }
  else if(buttonA.wasReleased()){
    turnScreenOff(false);    
    Serial.println("<<");
    // Hörbuchmodus --- temporäre Änderung!!!
    prevTrack();
    if(audio.isRunning()) audio.pauseResume();
    audio.connecttoSD(tracks[currentTrackNum].c_str(), restorePosition(tracks[currentTrackNum])); 
  }
  
  if(buttonB.pressedFor(1000)){
    turnScreenOff(false);    
    Serial.println("long press pause");
    buttonB.read();
  }
  else if(buttonB.wasReleased()){
    turnScreenOff(false);    
    Serial.println("pause");
    audio.pauseResume();
  }
  
  if(buttonC.pressedFor(1000)){
    turnScreenOff(false);    
    audio.setTimeOffset(30);
    buttonC.read();
  }
  else if(buttonC.wasReleased()){
    turnScreenOff(false);    
    // Hörbuchmodus --- temporäre Änderung!!!
    Serial.println(">>");
    nextTrack();
    if(audio.isRunning()) audio.pauseResume();
    audio.connecttoSD(tracks[currentTrackNum].c_str(), restorePosition(tracks[currentTrackNum]));
  }
  else if(buttonENC.wasReleased()){
    turnScreenOff(false);
    // Flip Screen
    if(tft.getRotation() == 1) tft.setRotation(3);
    else tft.setRotation(1);
    initGraphics();
    drawTapeSpools();
    drawProgressBar();
    drawTitleInfo();
  }  

  buttonA.read();
  buttonB.read();
  buttonC.read();
  buttonENC.read();
}

//*****************************************************************************************
//                                  E V E N T S                                           *
//*****************************************************************************************

void audio_info(const char *info){
  Serial.print("info        "); Serial.println(info);
  // Display the file name if id3 data is unavailable
  String infoString = (String)info;
  if(infoString.indexOf("file has no mp3") == 0){
    currentTitle = tracks[currentTrackNum].substring(1);
    currentArtist = "";
    drawTitleInfo();
  }
}
void audio_id3data(const char *info){  //id3 metadata
  Serial.print("id3data     ");Serial.println(info);
  
  String id3String = (String)info;
  if(id3String.indexOf("Title:") == 0){
    currentTitle = id3String.substring(7);
    drawTitleInfo();
  }
  else if(id3String.indexOf("Artist:") == 0){
    currentArtist = id3String.substring(8);
    drawTitleInfo();
  }
}
void audio_showstation(const char *info){
  Serial.print("station     ");Serial.println(info);
}
void audio_showstreamtitle(const char *info){
  Serial.print("streamtitle ");Serial.println(info);
}
void audio_bitrate(const char *info){
  Serial.print("bitrate     ");Serial.println(info);
}
void audio_commercial(const char *info){  //duration in sec
  Serial.print("commercial  ");Serial.println(info);
}
void audio_icyurl(const char *info){  //homepage
  Serial.print("icyurl      ");Serial.println(info);
}
void audio_lasthost(const char *info){  //stream URL played
  Serial.print("lasthost    ");Serial.println(info);
}
void audio_eof_speech(const char *info){
  Serial.print("eof_speech  ");Serial.println(info);
}
void audio_eof_mp3(const char * info){
  Serial.print("End of file");Serial.println(info);
  _f_eof = true;
}

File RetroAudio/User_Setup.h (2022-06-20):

//                            USER DEFINED SETTINGS
//   Set driver type, fonts to be loaded, pins used and SPI control method etc
//
//   See the User_Setup_Select.h file if you wish to be able to define multiple
//   setups and then easily select which setup file is used by the compiler.
//
//   If this file is edited correctly then all the library example sketches should
//   run without the need to make any more changes for a particular hardware setup!
//   Note that some sketches are designed for a particular TFT pixel width/height


// ##################################################################################
//
// Section 1. Call up the right driver file and any options for it
//
// ##################################################################################

// Define STM32 to invoke optimised processor support (only for STM32)
//#define STM32

// Defining the STM32 board allows the library to optimise the performance
// for UNO compatible "MCUfriend" style shields
//#define NUCLEO_64_TFT
//#define NUCLEO_144_TFT

// STM32 8 bit parallel only:
// If STN32 Port A or B pins 0-7 are used for 8 bit parallel data bus bits 0-7
// then this will improve rendering performance by a factor of ~8x
//#define STM_PORTA_DATA_BUS
//#define STM_PORTB_DATA_BUS

// Tell the library to use 8 bit parallel mode (otherwise SPI is assumed)
//#define TFT_PARALLEL_8_BIT

// Display type -  only define if RPi display
//#define RPI_DISPLAY_TYPE // 20MHz maximum SPI

// Only define one driver, the other ones must be commented out
//#define ILI9341_DRIVER       // Generic driver for common displays
//#define ILI9341_2_DRIVER     // Alternative ILI9341 driver, see https://github.com/Bodmer/TFT_eSPI/issues/1172
//#define ST7735_DRIVER      // Define additional parameters below for this display
//#define ILI9163_DRIVER     // Define additional parameters below for this display
//#define S6D02A1_DRIVER
//#define RPI_ILI9486_DRIVER // 20MHz maximum SPI
//#define HX8357D_DRIVER
//#define ILI9481_DRIVER
//#define ILI9486_DRIVER
//#define ILI9488_DRIVER     // WARNING: Do not connect ILI9488 display SDO to MISO if other devices share the SPI bus (TFT SDO does NOT tristate when CS is high)
//#define ST7789_DRIVER      // Full configuration option, define additional parameters below for this display
#define ST7789_2_DRIVER    // Minimal configuration option, define additional parameters below for this display
//#define R61581_DRIVER
//#define RM68140_DRIVER
//#define ST7796_DRIVER
//#define SSD1351_DRIVER
//#define SSD1963_480_DRIVER
//#define SSD1963_800_DRIVER
//#define SSD1963_800ALT_DRIVER
//#define ILI9225_DRIVER
//#define GC9A01_DRIVER

// Some displays support SPI reads via the MISO pin, other displays have a single
// bi-directional SDA pin and the library will try to read this via the MOSI line.
// To use the SDA line for reading data from the TFT uncomment the following line:

// #define TFT_SDA_READ      // This option is for ESP32 ONLY, tested with ST7789 and GC9A01 display only

// For ST7735, ST7789 and ILI9341 ONLY, define the colour order IF the blue and red are swapped on your display
// Try ONE option at a time to find the correct colour order for your display

// #define TFT_RGB_ORDER TFT_RGB  // Colour order Red-Green-Blue
// #define TFT_RGB_ORDER TFT_BGR  // Colour order Blue-Green-Red

// For M5Stack ESP32 module with integrated ILI9341 display ONLY, remove // in line below

// #define M5STACK

// For ST7789, ST7735, ILI9163 and GC9A01 ONLY, define the pixel width and height in portrait orientation
// #define TFT_WIDTH  80
// #define TFT_WIDTH  128
#define TFT_WIDTH  240 // ST7789 240 x 240 and 240 x 320
// #define TFT_HEIGHT 160
// #define TFT_HEIGHT 128
// #define TFT_HEIGHT 240 // ST7789 240 x 240
#define TFT_HEIGHT 320 // ST7789 240 x 320
// #define TFT_HEIGHT 240 // GC9A01 240 x 240

// For ST7735 ONLY, define the type of display, originally this was based on the
// colour of the tab on the screen protector film but this is not always true, so try
// out the different options below if the screen does not display graphics correctly,
// e.g. colours wrong, mirror images, or stray pixels at the edges.
// Comment out ALL BUT ONE of these options for a ST7735 display driver, save this
// this User_Setup file, then rebuild and upload the sketch to the board again:

// #define ST7735_INITB
// #define ST7735_GREENTAB
// #define ST7735_GREENTAB2
// #define ST7735_GREENTAB3
// #define ST7735_GREENTAB128    // For 128 x 128 display
// #define ST7735_GREENTAB160x80 // For 160 x 80 display (BGR, inverted, 26 offset)
// #define ST7735_REDTAB
// #define ST7735_BLACKTAB
// #define ST7735_REDTAB160x80   // For 160 x 80 display with 24 pixel offset

// If colours are inverted (white shows as black) then uncomment one of the next
// 2 lines try both options, one of the options should correct the inversion.

// #define TFT_INVERSION_ON
// #define TFT_INVERSION_OFF


// ##################################################################################
//
// Section 2. Define the pins that are used to interface with the display here
//
// ##################################################################################

// If a backlight control signal is available then define the TFT_BL pin in Section 2
// below. The backlight will be turned ON when tft.begin() is called, but the library
// needs to know if the LEDs are ON with the pin HIGH or LOW. If the LEDs are to be
// driven with a PWM signal or turned OFF/ON then this must be handled by the user
// sketch. e.g. with digitalWrite(TFT_BL, LOW);

// #define TFT_BL   17            // LED back-light control pin
// #define TFT_BACKLIGHT_ON HIGH  // Level to turn ON back-light (HIGH or LOW)
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

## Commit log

2022-07-14 Gerber RS274X files added
2022-08-29 BOM Updates with more Links and Details
    [Retro Audio Rev2.1 BOM.csv, Retro Audio Rev2.1.csv]
2022-08-29 BOM updated with more Details
    [Retro Audio Rev2.1 BOM.csv]
2022-09-24 Updated to show unused parts
    [Retro Audio Rev2.1.brd, Retro Audio Rev2.1.sch]
2022-12-28 Bug fixes, power saving and optimizations
    - Audio decoding in loop instead of thread -> no more crashes while fast forwarding
    - Auto screen off after 15 seconds
    [RetroAudio.ino]

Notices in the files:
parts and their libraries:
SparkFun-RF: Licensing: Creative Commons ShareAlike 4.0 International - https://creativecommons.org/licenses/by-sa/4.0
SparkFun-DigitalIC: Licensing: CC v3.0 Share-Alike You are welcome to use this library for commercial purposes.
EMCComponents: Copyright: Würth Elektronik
